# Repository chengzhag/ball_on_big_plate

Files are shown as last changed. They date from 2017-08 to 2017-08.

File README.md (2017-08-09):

# BallOnBigPlate
基于opencv的树莓派小球平衡控制项目，识别并定位小球在大平板上的位置，并通过串口发送给stm32f103单片机

## 整体方案

* 玻纤板做平板
    - 如果是舵机球头连杆驱动，需要设计舵机支架的安装、摇臂的转轴支撑
* 舵机驱动
    - 标准舵机：要求可控角度不大，因此可以考虑。球头连杆传动，力矩可变（舵机位置可调）
    - 直驱方式不太现实
* 树莓派opencv摄像头/电阻屏定位小球

## 计算机视觉方案

1. 阈值分割出平板
1. 检测平板轮廓，得到四个角点
1. 进行透视变换，消除平板角度影响
1. 全局寻找极小值，定位小球位置
1. 如果极小值较大，认为小球掉落

### 开发环境
- windows端搭建linux opencv交叉编译环境
- 树莓派搭载opencv3.2和鱼眼镜头
- 调试时采用socket+jpeg发送帧序列到windows server应用，黑白640*480分辨率下可以达到30帧

## 参考
- [基于Socket和OpenCV的实时视频传输（On Windows）](http://blog.csdn.net/pengz0807/article/details/52204134)
- [基于Socket和OpenCV的实时视频传输（On Linux）](http://blog.csdn.net/pengz0807/article/details/52204475)

# OpenCV_raspberry
为树莓派编译opencv，基于visualGDB的项目，不包含opencv源码和编译结果！！

## 简单使用
基于[官方教程](https://visualgdb.com/tutorials/raspberry/opencv/build/)建立opencv3交叉编译工程，所有软件均安装在默认目录

### 树莓派配置
1. 安装基于官方教程的镜像文件配置了opencv开发环境和依赖库的镜像

### windows端配置
1. 安装并破解visualGDB5.2r8（根据前面的经验，5.1版无法识别树莓派系统目录中的某些依赖库）
1. 解压打包好的opencv源码和编译好的动态链接库到D:\Program Files\OpenCV_3_2_0_source（为该工程中配置的opencv源码目录，不可更改）
1. 安装官网提供的[Raspberry / PI的Windows工具链](http://gnutoolchains.com/raspberry/)。下载  4.9.2	2016-09-23-raspbian-jessie (Raspberry Pi 1/2/3/Zero)	raspberry-gcc-4.9.2-r4.exe (738 MB)  并安装
1. 直接打开visual studio工程文件，右键工程名-visualGDB属性-Project settings-Deployment machine，设置目标树莓派的ip和账户、密码
1. 右键工程名-visualGDB属性-CMake project settings-同步sysroot-OK，大概耗时1小时。也可以直接复制拷贝的sysroot文件夹到C:\SysGCC\Raspberry\arm-linux-gnueabihf目录
1. 此时就可以进行编译了，如果报错，可能需要按照[官方教程](https://visualgdb.com/tutorials/raspberry/opencv/build/)第10步在windows端make install一下

## 经验与资料

### 树莓派配置：

1. 安装操作系统
    * Ubuntu MATE: https://ubuntu-mate.org/raspberry-pi/
    * Raspbian: https://www.raspberrypi.org/downloads/

2. 对操作系统进行简单配置
    * 从零开始搭建Raspberry Pi机器视觉编程环境: http://blog.csdn.net/iracer/article/details/51620051

3. 安装opencv相关库
    * 【教程】树莓派安装OS之后的初始配置，以安装OpenCV 3.1.0为例: http://www.jianshu.com/p/7afe8bfa26c0
    * 从零开始搭建Raspberry Pi机器视觉编程环境: http://blog.csdn.net/iracer/article/details/51620051

### vs配置：

1. 安装vs
2. 安装visualGDB最新版
3. 新建linux工程
    * 基础教程：
    * 
        * [Developing a Raspberry PI app with Visual Studio](https://visualgdb.com/tutorials/raspberry/)

    * 采用windows端交叉编译方案：
    * 
        * [交叉编译OpenCV 3为Raspberry Pi 2](https://visualgdb.com/tutorials/raspberry/opencv/build/)
        * [在Raspberry Pi上使用OpenCV库](https://visualgdb.com/tutorials/raspberry/opencv/)

4. 如何通过opencv调用树莓派摄像头：
    * [使用OpenCV与Raspberry Pi 2相机](https://visualgdb.com/tutorials/raspberry/opencv/camera/)
    * [使用Visual Studio的C ++程序的Raspberry Pi 2相机]（https://visualgdb.com/tutorials/raspberry/camera/）

5. 关于树莓派的windows工具链：
    * [Raspberry / PI的Windows工具链](http://gnutoolchains.com/raspberry/)

6. VisualGDB提供的官方兼容镜像：
    * [Raspberry Pi / Raspberry Pi 2 Jessie Image](http://gnutoolchains.com/raspberry/jessie/)

7. 关于其他树莓派库：
    * [使用WiringPi库与Raspberry PI交叉编译器](https://visualgdb.com/tutorials/raspberry/wiringPi/)
    * [为树莓PI创建“闪烁LED”项目](https://visualgdb.com/tutorials/raspberry/LED/)

### vs配置问题
按照[交叉编译OpenCV 3为Raspberry Pi 2](https://visualgdb.com/tutorials/raspberry/opencv/build/)教程配置后，编译失败？编译进行到一半提示"lib... needed by ... not found"（最后解决方法[修复与交叉编译器的路径链接问题](https://sysprogs.com/w/forums/topic/error-compile-with-open-cv-2-4/)

* 已检查下载了pkg-config-lite for windows并解压到了<sysgcc> \ Raspberry \ bin目录
* 已检查通过 sudo apt-get install libgtk2.0-dev安装了gtk2.0
* 已检查synchronize sysroot时包含了/ usr / share / pkgconfig和/ opt / vc目录
* 已为cmake设置环境变量：```PKG_CONFIG_SYSROOT_DIR=C:/SysGCC/Raspberry/arm-linux-gnueabihf/sysroot|PKG_CONFIG_PATH=C:/SysGCC/Raspberry/arm-linux-gnueabihf/sysroot/usr/lib/arm-linux-gnueabihf/pkgconfig;C:/SysGCC/Raspberry/arm-linux-gnueabihf/sysroot/usr/share/pkgconfig```
* 相似问题：
    * 官方文档：https://sysprogs.com/w/fixing-rpath-link-issues-with-cross-compilers/
    * [LD警告：LIB-XYZ，LIB-ABC需要 - CROSS COMP RASP PI"](https://sysprogs.com/w/forums/topic/ld-warning-lib-xyz-needed-by-lib-abc-cross-comp-rasp-pi/)
        * 但是cmake如何添加ldflags？如何更改library_names？

    * 根据[CANNOT COMPILE RASPICAM](https://sysprogs.com/w/forums/topic/error-compile-with-open-cv-2-4/)
        * 编译进行到一半提示lib... needed by ... not found
        * Hi,
Looks like your toolchain sysroot may have the incorrect linker configuration file. Please try updating to VisualGDB 5.2 and then resynchronize the sysroot. This should repair the config file automatically.

        * 下一步升级到visualGDB5.2尝试重新同步树莓派目录

编译好后的二进制可执行文件如何运行？

* chmod添加可执行权限：chmod 777 filename
* 执行：./filename 参数列表

# 例程

## OpenCVDemo
基于上述编译好后的opencv库的演示例程——canny边缘检测

## Raspicam
树莓派的C++摄像头库编译工程，支持opencv

## raspicam-0.1.6
被Raspicam引用，raspicam源码

- 在编译完成后，将生成的动态库libraspicam.so更名为libraspicam.so.0.1，和libraspicam_cv.so一起放入/usr/lib/raspicam文件夹。关于linux的动态库存放位置，看[Linux 里有/lib和/usr/lib，这两个目录下的库文件有什么区别吗？如果没区别为什么又要分开放呢](http://blog.csdn.net/fengyunjh/article/details/6232894)
- 然后按[linux找不到动态链接库 .so文件的解决方法](http://www.cnblogs.com/xudong-bupt/p/3698294.html)更新动态库搜索路径
- 关于linux下文件夹的创建和文件的移动看[Linux文件的复制、删除和移动命令使用说明](http://www.jb51.net/LINUXjishu/34936.html)

## RaspberryCameraTest
测试编译的Raspicam库，不依赖opencv

## OpenCVCameraDemo
基于opencv和Raspicam的边缘检测例程

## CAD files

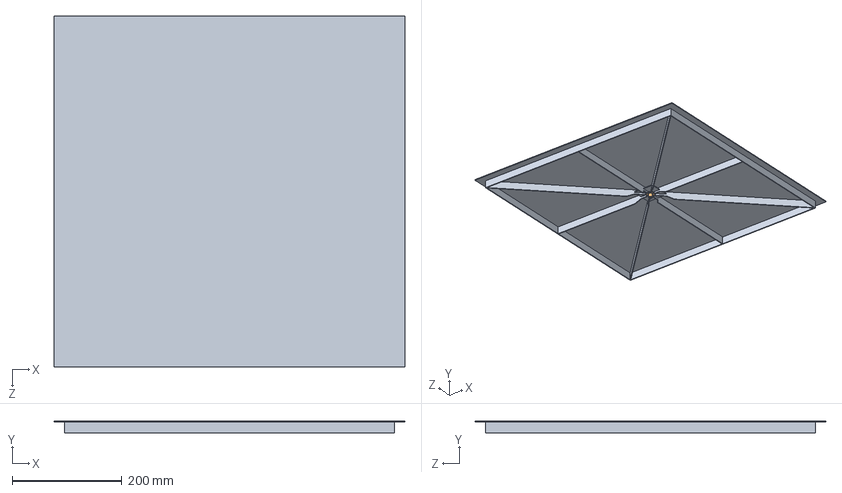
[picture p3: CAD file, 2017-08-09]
3d/平板/平板.SLDASM
640.0 x 22.0 x 640.0 mm
650板加强筋激光切割
法兰_5mm

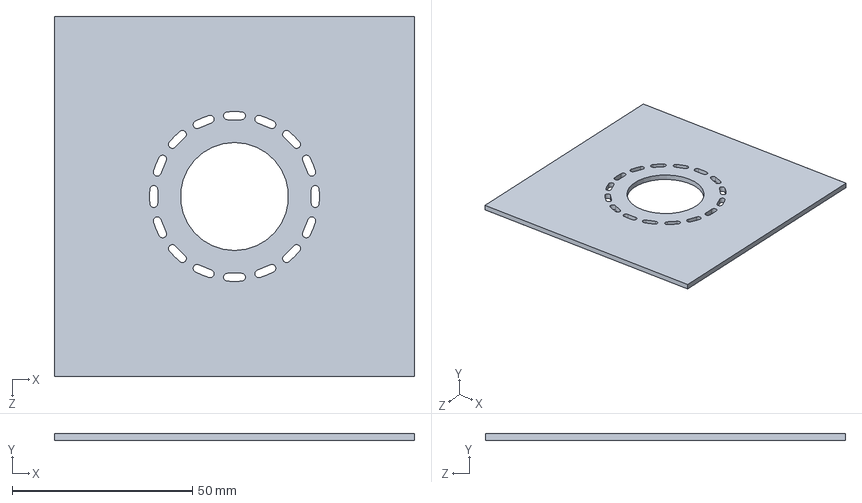
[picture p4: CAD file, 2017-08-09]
3d/圆形喷漆模具.SLDPRT
100.0 x 2.00 x 100.0 mm

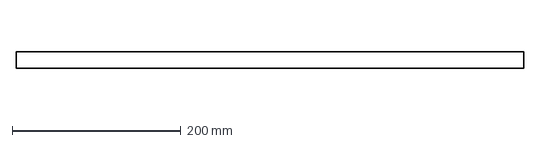
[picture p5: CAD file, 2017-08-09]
3d/平板/草稿/650板加强筋激光切割_边缘加强筋.DXF
602.0 x 20.0 mm

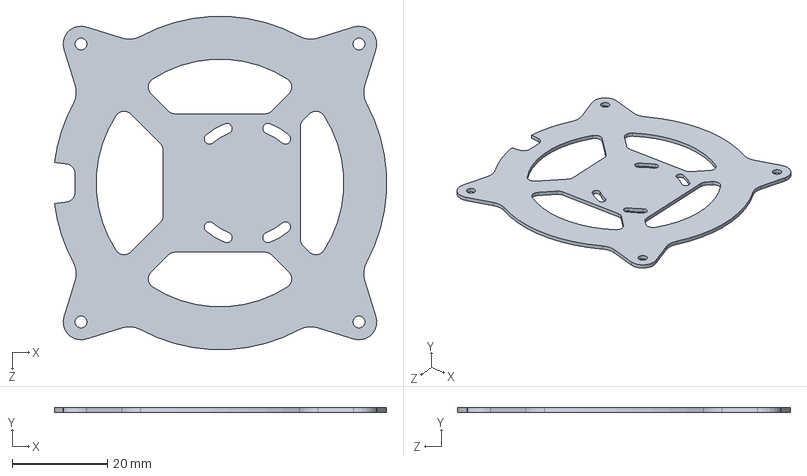
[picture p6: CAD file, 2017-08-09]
3d/摄像头补光灯固定板.SLDPRT
69.7 x 1.00 x 69.9 mm

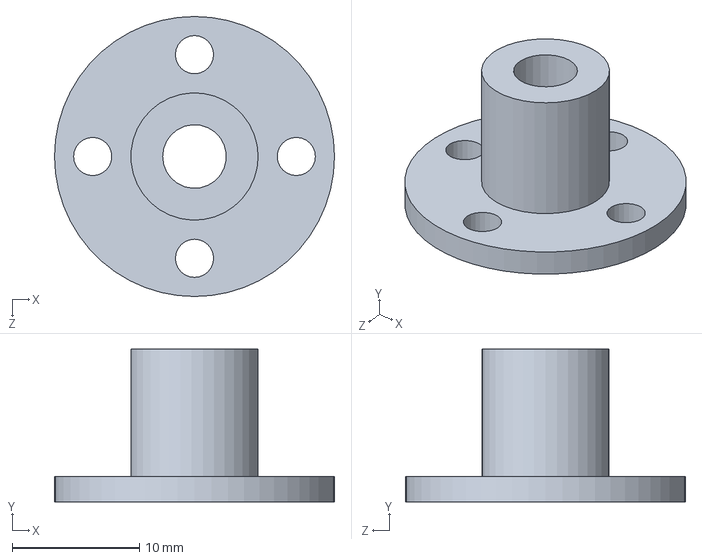
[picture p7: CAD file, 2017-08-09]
3d/平板/法兰_5mm.SLDPRT
22.0 x 12.0 x 22.0 mm

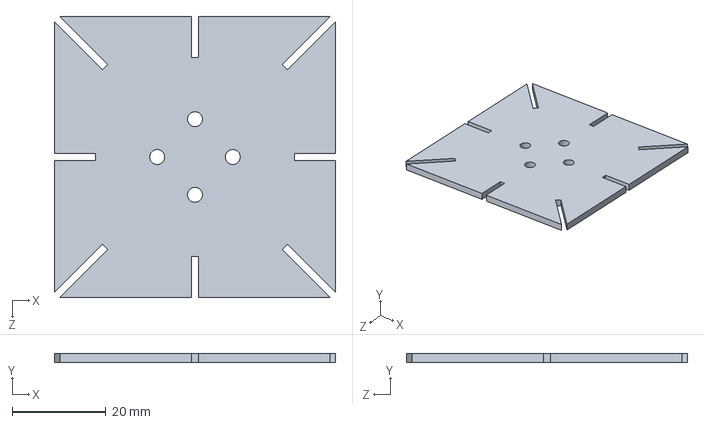
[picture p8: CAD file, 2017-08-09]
3d/平板/草稿/650板加强筋激光切割_中央固定板.SLDPRT
60.0 x 2.00 x 60.0 mm

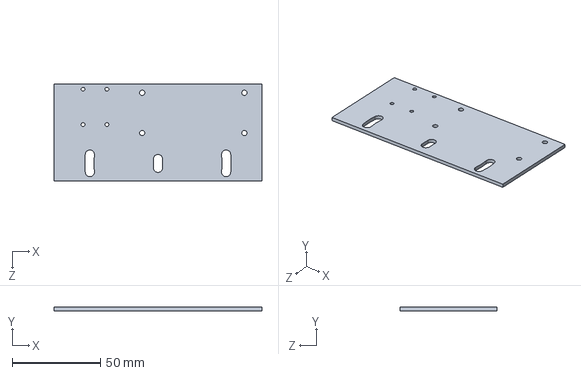
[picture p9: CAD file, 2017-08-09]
3d/摄像头固定板.SLDPRT
117.9 x 2.00 x 55.0 mm

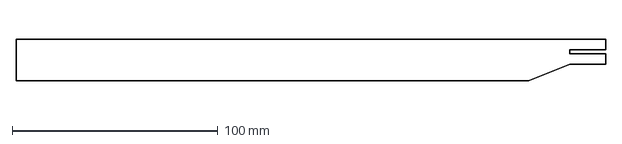
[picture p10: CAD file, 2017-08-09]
3d/平板/草稿/650板加强筋激光切割_中间加强筋.DXF
286.5 x 20.0 mm

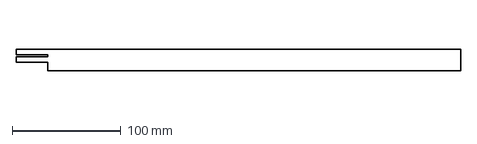
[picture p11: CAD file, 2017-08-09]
3d/平板/草稿/650板加强筋激光切割_45加强筋.DXF
409.4 x 20.0 mm

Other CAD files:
3d/平板/草稿/支撑底板.DWG
3d/平板/650板加强筋激光切割.SLDPRT
3d/树莓派摄像头.SLDPRT
3d/圆形喷漆模具.DXF
3d/平板/650板加强筋激光切割.dwg
3d/平板/650板加强筋激光切割.dxf
3d/平板/草稿/650板加强筋激光切割_45加强筋.dwg
3d/平板/草稿/650板加强筋激光切割_中央固定板.DXF
3d/平板/草稿/650板加强筋激光切割_中央固定板.dwg
3d/平板/草稿/650板加强筋激光切割_中间加强筋.dwg
3d/平板/草稿/650板加强筋激光切割_边缘加强筋.dwg
3d/摄像头固定板.DXF
3d/摄像头补光灯固定板.DXF

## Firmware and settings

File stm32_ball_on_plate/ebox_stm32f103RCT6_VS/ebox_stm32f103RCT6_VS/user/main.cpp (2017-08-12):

#include "ebox.h"
#include "ball_on_plate.h"

//调试
#include "led.h"
#include "uart_vcan.h"

#include "my_math.h"
#include "signal_stream.h"
#include <math.h>

//交互
#include "Button.h"
#include "oled_i2c.h"
//操作系统
#include "freertos.h"
#include "task.h"
#include "queue.h"


using namespace std;

BallOnPlate ballOnPlate;

//调试
UartVscan uartVscan(&uart1);
FpsCounter fpsUI;
float fpsUItemp;
float outX, outY;

//交互
const float rateUI = 10;
const float intervalUI = 1 / rateUI;
const uint32_t uiRefreshDelay = ((1000 * intervalUI + 0.5) / portTICK_RATE_MS);
Button keyL(&PB4, 1);
Button keyR(&PB1, 1);
Button keyU(&PC5, 1);
Button keyD(&PC2, 1);
Led led(&PD2, 1);
OLEDI2C oled(&i2c1);


//按键交互
int numIndex = 0;
int task = 0;
TicToc timerTask,timerUI;
int stage = 0;//任务的状态，0代表停止，1代表准备完毕
bool caliSuc = true, caliBegin = false;

//路径参数
int abcd[4] = { 0 };
const float speedTask6=120;

void posReceiveEvent()
{
	//按键响应
	keyL.loop();
	keyR.loop();
	keyU.loop();
	keyD.loop();

	if (keyR.click())
	{
		numIndex++;
	}
	if (keyL.click())
	{
		numIndex--;
	}

	limit<int>(numIndex, 0, 7);

	//总共7个部分，0部分用作调试
	//按键响应
	float increase = 0;
	if (keyU.click())
	{
		increase++;
	}
	if (keyD.click())
	{
		increase--;
	}
	if (keyU.pressed_for(200, 0))
	{
		increase += 1;
	}
	if (keyD.pressed_for(200, 0))
	{
		increase -= 1;
	}



	switch (numIndex)
	{
	case 0:
		stage = 0;//停止进行中的任务
		task += increase;
		limit(task, 0, 7);
		break;
	case 1:
		//选择键按下
		if (increase != 0)
		{
			//开始任务
			switch (task)
			{
			case 0://任务0，归中
				if (!ballOnPlate.getIsBallOn())//防止准备时速度太快冲出平板
				{
					ballOnPlate.setPath(4, 4, 100);
				}
				else
				{
					ballOnPlate.setPath(4, 100);
				}
				stage = 1;
				break;
			case 1://任务1，2稳定5
				if (!ballOnPlate.getIsBallOn())
				{
					ballOnPlate.setPath(1, 1, 100);
				}
				else
				{
					ballOnPlate.setPath(1, 100);
				}
				stage = 1;
				break;
			case 2://任务2，1~5停留2<15
				if (stage == 0)
				{
					if (!ballOnPlate.getIsBallOn())
					{
						ballOnPlate.setPath(0, 0, 100);
					}
					else
					{
						ballOnPlate.setPath(0, 100);
					}
					stage = 1;
				}
				else if (stage == 1)
				{
					timerUI.tic();
					ballOnPlate.setPath(0, 4, 100);
					stage = 2;
				}
				break;
			case 3://任务3，1~4停留2~5停留2<20
				if (stage == 0)
				{
					if (!ballOnPlate.getIsBallOn())
					{
						ballOnPlate.setPath(0, 0, 100);
					}
					else
					{
						ballOnPlate.setPath(0, 100);
					}
					stage = 1;
				}
				else if (stage == 1)
				{
					timerUI.tic();
					ballOnPlate.setPath(0, 3, 100);
					timerTask.tic();
					stage = 2;
				}
				break;
			case 4://任务4，1~9停留2<30
				if (stage == 0)
				{
					if (!ballOnPlate.getIsBallOn())
					{
						ballOnPlate.setPath(0, 0, 100);
					}
					else
					{
						ballOnPlate.setPath(0, 100);
					}
					stage = 1;
				}
				else if (stage == 1)
				{
					timerUI.tic();
					ballOnPlate.setPath(0, 8, 100);
					stage = 2;
				}
				
				break;
			case 5://任务5，1~2~6~9停留2<40
				if (stage == 0)
				{
					if (!ballOnPlate.getIsBallOn())
					{
						ballOnPlate.setPath(0, 0, 100);
					}
					else
					{
						ballOnPlate.setPath(0, 100);
					}
					stage = 1;
				}
				else if (stage == 1)
				{
					timerUI.tic();
					ballOnPlate.setPath(0, 1, 100);
					timerTask.tic();
					stage = 2;
				}
				break;
			case 6://任务6，手动输入先后经过ABCD
				if (stage == 0)
				{
					if (!ballOnPlate.getIsBallOn())
					{
						ballOnPlate.setPath(abcd[0], abcd[0], speedTask6);
					}
					else
					{
						ballOnPlate.setPath(abcd[0], speedTask6);
					}
					
					stage = 1;
				}
				else if (stage == 1)
				{
					timerUI.tic();
					ballOnPlate.setPath(abcd[0], abcd[1], speedTask6);
					timerTask.tic();
					stage = 2;
				}
				break;
			case 7://任务7，4~绕5 3周以上~9停留2
				if (stage == 0)
				{
					if (!ballOnPlate.getIsBallOn())
					{
						ballOnPlate.setPath(3, 3, 100);
					}
					else
					{
						ballOnPlate.setPath(3, 100);
					}
					stage = 1;
				}
				else if (stage == 1)
				{
					timerUI.tic();
					timerTask.tic();
					ballOnPlate.setPath(3, 11, 75);
					stage = 2;
				}
				break;
			default:
				break;
			}
		}
		break;
	case 2://A
		stage = 0;
		abcd[0] += increase;
		limit(abcd[0], 0, 8);
		break;
	case 3://B
		stage = 0;
		abcd[1] += increase;
		limit(abcd[1], 0, 8);
		break;
	case 4://C
		stage = 0;
		abcd[2] += increase;
		limit(abcd[2], 0, 8);
		break;
	case 5://D
		stage = 0;
		abcd[3] += increase;
		limit(abcd[3], 0, 8);
		break;
	case 6:
		if (increase != 0)
		{
			ballOnPlate.shutdownRasp();
		}
		break;
	case 7:
		if (increase != 0)
		{
			caliBegin = true;
		}
		break;
	default:
		break;
	}

	switch (task)
	{
	case 1:
		if (stage == 1 && !ballOnPlate.getIsBallOn())
		{
			timerUI.tic();
			stage = 2;
		}
		else if (stage == 2 && ballOnPlate.getIsBallOn())
		{
			stage = 1;
		}
		break;
	case 3:
		if (timerTask.toc() > 7000 && stage == 2)
		{
			ballOnPlate.setPath(3, 4, 100);
			stage = 3;
		}
		break;
	case 5:
		if (timerTask.toc() > 3000 && stage == 2)
		{
			ballOnPlate.setPath(1, 5, 100);
			stage = 3;
			timerTask.tic();
		}
		else if (timerTask.toc() > 4000 && stage == 3)
		{
			ballOnPlate.setPath(5, 8, 100);
			stage = 4;
		}
		break;
	case 6:
		if (timerTask.toc() > 6000 && stage == 2)
		{
			ballOnPlate.setPath(abcd[1], abcd[2], speedTask6);
			stage = 3;
			timerTask.tic();
		}
		else if (timerTask.toc() > 6000 && stage == 3)
		{
			ballOnPlate.setPath(abcd[2], abcd[3], speedTask6);
			stage = 4;
		}
		break;
	case 7:
		if (timerTask.toc() > 2000 && stage == 2)
		{
			ballOnPlate.setRoundParams(100, 0.2);
			ballOnPlate.setMode(BallOnPlate_Pos_Mode_Round);
			stage = 3;
			timerTask.tic();
		}
		break;
	default:
		break;
	}

	
	float vscan[] = {
		ballOnPlate.getPosX(),ballOnPlate.getPosY()
		,ballOnPlate.getOutX(),ballOnPlate.getOutY()
		,ballOnPlate.getTargetXRaw(),ballOnPlate.getTargetYRaw()
		//,ballOnplate.getFeedforwardX(),ballOnplate.getFeedforwardY()
		,ballOnPlate.getTargetXFiltered(),ballOnPlate.getTargetYFiltered()
	};
	uartVscan.sendOscilloscope(vscan, 8);

	//调试
	outX = ballOnPlate.getOutX();
	outY = ballOnPlate.getOutY();
}


//校准平板任务
void caliTask(void *pvParameters)
{
	portTickType xLastWakeTime;
	xLastWakeTime = xTaskGetTickCount();
	while (1)
	{
		if (caliBegin)
		{
			caliSuc = ballOnPlate.calibrate();
			caliBegin = false;
		}
	}
}

//UI交互
void uiRefresh(void *pvParameters)
{
	portTickType xLastWakeTime;
	xLastWakeTime = xTaskGetTickCount();

	while (1)
	{
		float fpsPIDtemp;
		//判断是否树莓派已关机
		if (!ballOnPlate.getIsPosReceiving())
		{
			fpsPIDtemp = 0;
		}
		else
		{
			fpsPIDtemp = ballOnPlate.getFps();
		}

		//显示任务标号
		oled.printf(0, 0, Oledi2c_Font_8x16, "task:");
		if (numIndex != 0)
		{
			oled.printf(40, 0, Oledi2c_Font_8x16, "%d",task);
		}
		else
		{
			oled.printf(40, 0, Oledi2c_Font_8x16_Inv, "%d", task);
		}

		//显示开始按键
		if (numIndex != 1)
		{
			if (stage == 0)
			{
				oled.printf(64, 0, Oledi2c_Font_8x16, "start   ");
			}
			else if (stage == 1)
			{
				oled.printf(64, 0, Oledi2c_Font_8x16, "ready   ");
			}
			else if (stage >= 2)
			{
				oled.printf(64, 0, Oledi2c_Font_8x16, "working ");
			}
			
		}
		else
		{
			if (stage == 0)
			{
				oled.printf(64, 0, Oledi2c_Font_8x16_Inv, "start");
			}
			else if (stage == 1)
			{
				oled.printf(64, 0, Oledi2c_Font_8x16_Inv, "ready");
			}
			else if (stage >= 2)
			{
				oled.printf(64, 0, Oledi2c_Font_8x16_Inv, "working");
			}
		}

		//显示4位数
		for (int i = 0; i < 4; i++)
		{
			if (numIndex - 2 == i)
			{
				oled.printf(i * 8, 2, Oledi2c_Font_8x16_Inv, "%1d",abcd[i]+1);
			}
			else
			{
				oled.printf(i * 8, 2, Oledi2c_Font_8x16, "%1d", abcd[i] + 1);
			}
			
		}

		//显示关机按键
		if (numIndex==6)
		{
			oled.printf(0, 4, Oledi2c_Font_6x8_Inv, "shutdown");
		}
		else
		{
			oled.printf(0, 4, Oledi2c_Font_6x8, "shutdown");
		}
		
		//显示校准按键
		if (numIndex == 7)
		{
			oled.printf(72, 4, Oledi2c_Font_6x8_Inv, "cali");
		}
		else
		{
			oled.printf(72, 4, Oledi2c_Font_6x8, "cali");
		}

		if (caliSuc)
		{
			oled.printf(104, 4, Oledi2c_Font_6x8, "Suc");
		}
		else
		{
			oled.printf(104, 4, Oledi2c_Font_6x8, "Fai");
		}

		//显示计时
		if (stage >= 2)
		{
			oled.printf(64, 2, Oledi2c_Font_8x16, "%-8.1f", (float)timerUI.toc()/1000);
		}
		oled.printf(0, 5, Oledi2c_Font_6x8, "%-8.1f%-8.1f", ballOnPlate.getTargetXRaw(), ballOnPlate.getTargetYRaw());
		oled.printf(0, 6, Oledi2c_Font_6x8, "%-8.1f%-8.1f", ballOnPlate.getPosX(), ballOnPlate.getPosY());
		fpsUItemp = fpsUI.getFps();
		oled.printf(0, 7, Oledi2c_Font_6x8, "%-8.0f%-8.0f", fpsPIDtemp, fpsUItemp);

		vTaskDelayUntil(&xLastWakeTime, uiRefreshDelay);
	}

}

void setup()
{
	ebox_init();
	ballOnPlate.attachAfterPIDEvent(posReceiveEvent);
	ballOnPlate.begin();
	ballOnPlate.setCaliParams(-2, 0, 24, 22);
	ballOnPlate.setPath(4, 4, 100);//归中


	//调试
	uart1.begin(115200);
	fpsUI.begin();


	//交互
	keyD.begin();
	keyL.begin();
	keyR.begin();
	keyU.begin();
	led.begin();
	oled.begin();

	set_systick_user_event_per_sec(configTICK_RATE_HZ);
	attach_systick_user_event(xPortSysTickHandler);
	xTaskCreate(uiRefresh, "uiRefresh", 512, NULL, 0, NULL);
	xTaskCreate(caliTask, "caliTask", 512, NULL, 0, NULL);
	vTaskStartScheduler();
}


int main(void)
{
	setup();


	while (1)
	{

	}

}

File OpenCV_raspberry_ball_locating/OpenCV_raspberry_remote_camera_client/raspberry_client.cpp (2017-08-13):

#include <ctime>
#include <iostream>
#include <stdio.h>
#include <raspicam_cv.h>
#include "opencv2/highgui/highgui.hpp"
#include "opencv2/imgproc/imgproc.hpp"
#include <vector>

#include "SocketMatTransmissionClient.h"  

#include "my_opencv.h"
#include "my_math.h"
#include <math.h>
#include <algorithm>
#include "uart_num.h"

#include "wiringPi.h"
#include "wiringSerial.h"


using namespace cv;
using namespace std;

//#define STDIO_DEBUG
//#define SOCKET_SEND_IMAGE
#define FINAL_RELEASE


int main(int argc, char **argv)
{
#ifndef FINAL_RELEASE
	system("sudo killall ball");	  
#endif // !FINAL_RELEASE

	piHiPri(99);//最高优先级
	///声明变量
#ifdef SOCKET_SEND_IMAGE
	cout << "socket connecting..." << endl;
	SocketMatTransmissionClient socketMat;
	socketMat.begin("192.168.2.100");
#endif // SOCKET_SEND_IMAGE
	//摄像头
	raspicam::RaspiCam_Cv cam;
	//参数设置
	float imRawFactor = 0.2;
	cam.set(CV_CAP_PROP_FORMAT, CV_8UC1);
	cam.set(CV_CAP_PROP_FRAME_WIDTH, cam.get(CV_CAP_PROP_FRAME_WIDTH) * imRawFactor);
	cam.set(CV_CAP_PROP_FRAME_HEIGHT, cam.get(CV_CAP_PROP_FRAME_HEIGHT) * imRawFactor);
	int imRawH = cam.get(CV_CAP_PROP_FRAME_HEIGHT),
		imRawW = cam.get(CV_CAP_PROP_FRAME_WIDTH);
	Mat imRaw;
	
	//畸变矫正
	Mat cameraMatrix = Mat::eye(3, 3, CV_64F);
	cameraMatrix.at<double>(0, 0) = 7.428373545192941e02*imRawFactor;
	cameraMatrix.at<double>(0, 1) = 0.950790070584049*imRawFactor;
	cameraMatrix.at<double>(0, 2) = 6.631483964605850e02*imRawFactor;
	cameraMatrix.at<double>(1, 1) = 7.427433947316842e02*imRawFactor;
	cameraMatrix.at<double>(1, 2) = 4.342201658042163e02*imRawFactor;
	
	Mat distCoeffs = Mat::zeros(5, 1, CV_64F);
	distCoeffs.at<double>(0, 0) = -0.290711633529124;
	distCoeffs.at<double>(1, 0) = 0.056979441111773;
	distCoeffs.at<double>(2, 0) = -2.656378643258185e-04;
	distCoeffs.at<double>(3, 0) = 0.001513705053758;
	distCoeffs.at<double>(4, 0) = 0;
	
	Mat map1, map2;
	Size imRawSize(imRawW, imRawH);
	initUndistortRectifyMap(cameraMatrix,
		distCoeffs,
		Mat(),
		getOptimalNewCameraMatrix(cameraMatrix, distCoeffs, imRawSize, 1, imRawSize, 0),
		imRawSize,
		CV_16SC2,
		map1,
		map2);
	
	//剪切平板位置图像
	float plateRegionHeight = 0.55;//, plateRegionWidth = 0.52;
	float plateRegionOffH = -0.033, plateRegionOffW = 0.03;
	Rect plateRegion(
		int(imRawW*(0.5 + plateRegionOffW) - imRawH*plateRegionHeight / 2),
		int(imRawH*(0.5 + plateRegionOffH - plateRegionHeight / 2)),
		imRawH*plateRegionHeight,
		imRawH*plateRegionHeight);
	imRawW = plateRegion.width;
	imRawH = plateRegion.height;
	
	//平板小球尺寸信息
	const float maxX = 600, maxY = 600;
	const float camHeight = 430;
	const float ballArea = 30;
	const float ballAreaLow = ballArea * 0.2;
	const float ballAreaHigh = ballArea * 5;
	
	
#ifdef SOCKET_SEND_IMAGE
	//发送图像，用于测试
	Mat imSend;
#endif // SOCKET_SEND_IMAGE
	

	
	///预处理
	Mat imProcess;
	const int structElementSize = 1;
	Mat element = getStructuringElement(MORPH_ELLIPSE,  
		Size(2*structElementSize + 1, 2*structElementSize + 1),  
		Point(structElementSize, structElementSize));
	
	
	///初始化
	//初始化连接
	if (!cam.open())
		return 1;
	
	//初始化串口
	UartNum<float> uart;
	uart.begin(9600);
	
	//初始化阈值，固定二值化阈值，减轻后面计算负担
	const int structElementSizePre = 20;
	Mat elementPre = getStructuringElement(MORPH_ELLIPSE,  
		Size(2*structElementSize + 1, 2*structElementSize + 1),  
		Point(structElementSize, structElementSize));
	double threshBinary = 0;
	for (int i = 0; i < 60; i++)
	{
		cam.grab();
		cam.retrieve(imRaw);
		if (imRaw.empty())
		{
			cout << "imRaw为空！！！" << endl;
			return 1;
		}
		remap(imRaw, imRaw, map1, map2, INTER_LINEAR);//INTER_NEAREST
		imRaw = imRaw(plateRegion);
		morphologyEx(imRaw, imRaw, CV_MOP_DILATE, elementPre);
		
		double minBrightness;
		minMaxLoc(imRaw, &minBrightness, NULL, NULL, NULL);
		threshBinary += minBrightness; 
		
#ifdef SOCKET_SEND_IMAGE
		//发送图像，用于测试
//		threshold(imTrans, imSend, threshBinary, 255, CV_THRESH_BINARY);
		socketMat.transmit(imRaw, 80);
#endif // SOCKET_SEND_IMAGE
	}
	threshBinary /= 60;
	threshBinary -= 10;

	double timeStart = 0, timeEnd = 0;

	
	
	while (1)
	{
		cam.grab();
		cam.retrieve(imRaw);

		if (imRaw.empty())
		{
			cout << "imRaw为空！！！" << endl;
			return 1;
		}
		
		remap(imRaw, imRaw, map1, map2, INTER_LINEAR);//INTER_NEAREST
		imRaw = imRaw(plateRegion);
			
		
		/// 小球定位算法开始
		float pos[2];
		morphologyEx(imRaw, imProcess, CV_MOP_ERODE, element);
//		resize(imRaw, imThresh, Size(0, 0), resizeThresh, resizeThresh, INTER_NEAREST);
		threshold(imProcess, imProcess, threshBinary, 255, CV_THRESH_BINARY_INV);
//		threshold(imThresh, imThresh, 0, 255, CV_THRESH_OTSU);
//		morphologyEx(imRaw, imProcess, CV_MOP_TOPHAT, element);
//		medianBlur(imProcess, imProcess, 9);
//		GaussianBlur(imRaw, imProcess, 
//			Size(int(0.01*imRawH) * 2 + 1, int(0.01*imRawW) * 2 + 1), 
//			int(0.01*imRawW) * 2 + 1, int(0.01*imRawW) * 2 + 1);
		//以小球半径的两倍为窗口长度
		
		//计算二值图形的矩特征
		Moments mu = moments(imProcess, true);
		Point2f ballPoint(mu.m10 / mu.m00, mu.m01 / mu.m00);
		pos[0] = ballPoint.x;
		pos[1] = ballPoint.y;
		//通过面积判断是否有干扰
		float darkArea = mu.m00;
		if (darkArea > ballAreaHigh || darkArea < ballAreaLow)
		{
			pos[0] = 0.0 / 0.0;
			pos[1] = 0.0 / 0.0;
		}
	
		
////		轮廓提取
//		vector<vector<Point> > contours;
//		findContours(imProcess, contours, CV_RETR_EXTERNAL, CV_CHAIN_APPROX_NONE);

		
//		Point ballPoint;
//		double minBrightness;
//		minMaxLoc(imProcess, &minBrightness, NULL, &ballPoint, NULL);
//		if (minBrightness < 30)
//		{
//			pos[0] = ballPoint.x;
//			pos[1] = ballPoint.y;
//		}
//		else
//		{
//			pos[0] = -1;
//			pos[1] = -1;
//		}//如果最小亮度过高，认为小球掉落

	
		//标准化坐标单位mm
		pos[0] = pos[0]*maxX / imProcess.rows;
		pos[1] = pos[1]*maxY / imProcess.cols;
		pos[0] = 430*tan(-0.6092 + pos[0]  * 0.6092 / 300) + maxX / 2;
		pos[1] = 430*tan(-0.6092 + pos[1]  * 0.6092 / 300) + maxY / 2;
		
		
#ifdef STDIO_DEBUG
		timeEnd = (double)getTickCount();
		//计算算法帧率
		cout << "fps: " << 1.0 / (timeEnd - timeStart)*(double)getTickFrequency()
				<< "\t" << pos[0] << " of " << maxX 
				<< "\t" << pos[1] << " of " << maxX
				<< "\t" << "thres: " << threshBinary 
				<< "\t" << "darkArea:" << darkArea
				<< endl;
		timeStart = timeEnd;
#endif // STDIO_DEBUG

		uart.sendNum(pos, 2);

		///小球定位算法结束
		
		
		
#ifdef SOCKET_SEND_IMAGE
		//发送图像，用于测试
		resize(imProcess, imSend, Size(0, 0), 1, 1, INTER_NEAREST);
//		threshold(imTrans, imSend, threshBinary, 255, CV_THRESH_BINARY);
		socketMat.transmit(imSend, 80);
#endif // SOCKET_SEND_IMAGE
		
		//判断单片机发来的关机指令或按键发来的关机指令
		int fd = uart.getFd();
		if (int num = serialDataAvail(fd) > 0)
		{
			char c;
			c = serialGetchar(fd);
			for (int i = 1; i < num; i++)
			{
				serialGetchar(fd);
			}
			if (c == 's')
			{
				system("sudo shutdown -h now");
			}
//			else if (c == 'k')
//			{
//				system("sudo killall OpenCVCameraDemo");
//			}
		}
		
		
		
	}
#ifdef SOCKET_SEND_IMAGE
	socketMat.disconnect();
#endif // SOCKET_SEND_IMAGE
	cam.release();
	return 0;
}

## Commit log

2017-08-09 初始化工程，添加树莓派、stm32工程，题目文档
    [摄像头固定板.DXF, 摄像头固定板.SLDPRT, 摄像头补光灯固定板.DXF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]
2017-08-09 更新摄像头补光灯固定板，添加圆形模具
    [圆形喷漆模具.DXF, 圆形喷漆模具.SLDPRT, 摄像头补光灯固定板.SLDPRT]
2017-08-09 更新摄像头补光灯固定板
    [摄像头补光灯固定板.DXF]
2017-08-09 更新摄像头畸变校准参数
    [650板加强筋激光切割.SLDPRT, 650板加强筋激光切割.dwg, 650板加强筋激光切割.dxf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]
2017-08-09 更新650板加强筋设计
    [650板加强筋激光切割.dwg, 650板加强筋激光切割.dxf]
2017-08-09 消除工程转移过程中临时文件带来的错误
2017-08-10 针对大板对小球定位程序进行微调，添加干扰判断代码
2017-08-10 去除mpu底座倾斜补偿，针对新结构进行简单PID调整。TODO：进行精细PID调整
2017-08-10 精调PID。TODO：封装平板小球类，添加特殊设计的专家PID
2017-08-10 完成平板小球基类的封装，未测试
2017-08-10 完成main.h的改造，测试已封装的平板小球类，添加几个接口
2017-08-10 添加方便调试的树莓派杀死进程代码
2017-08-10 添加平板小球专用PID
2017-08-11 改进平板小球专用PID。TODO：设计路径生成函数
2017-08-11 添加一维路径生成
2017-08-11 添加两点之间路径点下标生成
2017-08-11 更新一维路径生成类，添加结束判断
2017-08-11 完成两点间平滑路径的生成
2017-08-11 添加融合路径设置的小球平板
2017-08-11 修复一些平板小球的bug。TODO：对main.c进行重构
2017-08-11 添加任务1~6的逻辑，修复平板小球路线的bug。TODO：添加任务7的逻辑，改进PID精度
2017-08-11 添加安全区和圆圈之间的路径生成
2017-08-11 修复部分安全区路径错误。TODO：取消4点方案，改用圆形方案
2017-08-11 更新树莓派自启程序，去掉安全区路径生成
2017-08-11 添加关机按键
2017-08-12 添加第7题绕圈特例，完成题目逻辑
2017-08-12 添加自校准程序。TODO：设计PID
2017-08-12 完成PID精调
2017-08-12 降低串口波特率至9600，修复偶尔因传输受扰导致的错误
2017-08-12 以树莓派自启方式编译
2017-08-13 针对实际光线情况对小球面积范围作了适当的扩大
